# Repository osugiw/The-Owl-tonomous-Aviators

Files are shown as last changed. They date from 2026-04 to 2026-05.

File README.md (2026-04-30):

# Owl-tonomous Car 🚗🦉

This project implements a small autonomous vehicle capable of following a predefined track using computer vision and control techniques. The system was developed as part of the ELEC 553 course.

## Overview

The vehicle uses a camera and onboard processing (Raspberry Pi) to detect lane markings and navigate the track in real time. Steering and speed are controlled using PID controllers, enabling stable and smooth motion.

## Features

- Lane detection using OpenCV and HSV color segmentation  
- Polynomial fitting for trajectory estimation  
- Steering control using PID  
- Speed regulation using an optical encoder for feedback  
- Red signal detection for stop behavior  
- Object detection using YOLOv5 on Raspberry Pi  

## System Architecture

- **Camera**: captures real-time video of the track  
- **Raspberry Pi**: processes images and runs control algorithms  
- **Servo Motor**: controls steering  
- **DC Motor**: drives the vehicle forward  
- **Optical Encoder**: measures motor speed for closed-loop control  

## Lane Detection

The system detects blue tape marking the track using HSV color segmentation. A region of interest is applied to focus on relevant areas of the image. Detected lane pixels are used to fit second-order polynomials, and the center trajectory is computed from the lane boundaries. A look-ahead point is then used to estimate the steering angle.

## Control

Steering is controlled using a PID controller based on the difference between the desired heading (straight) and the estimated steering angle. Speed is regulated using a second PID loop, which uses feedback from an optical encoder to maintain a target RPM.

## Red Signal Detection

Red markers placed on the track are detected using color segmentation. The first detected marker causes the vehicle to stop briefly before continuing, while the second marker triggers a full stop.

## Object Detection

The system also integrates object detection using YOLOv5 running on the Raspberry Pi. The official Ultralytics repository was used, and images were resized to 320×320 for efficient inference. The system achieves approximately 3.8 FPS on test images, with performance varying during live streaming due to latency and hardware constraints.

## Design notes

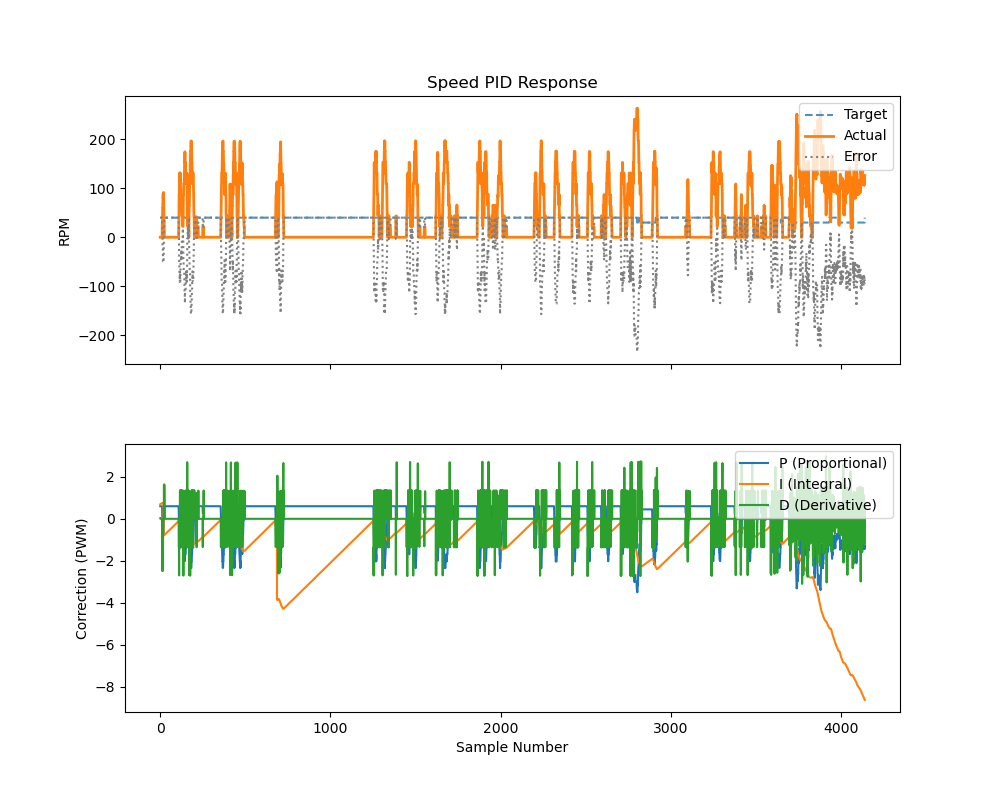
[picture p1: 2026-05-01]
PID_speed.png

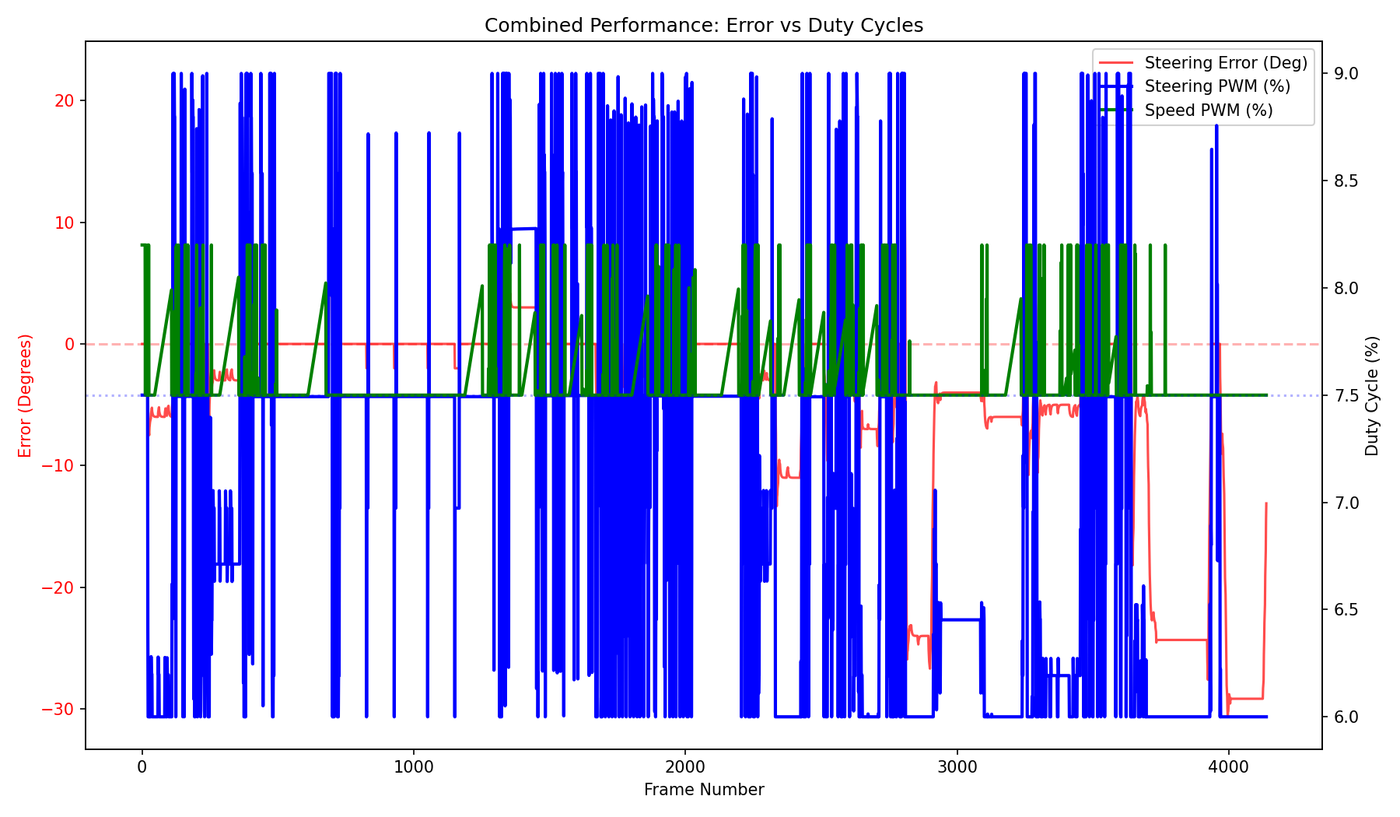
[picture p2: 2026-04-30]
DutyCycle_SpeedSteering.png

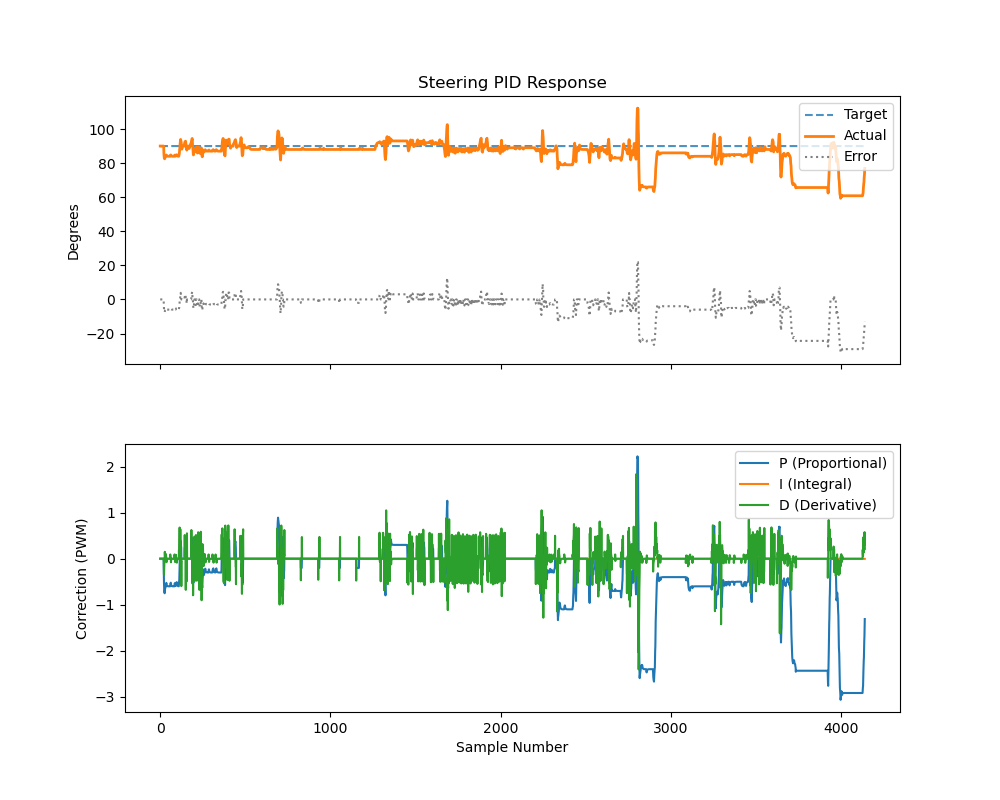
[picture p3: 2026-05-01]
PID_steering.png

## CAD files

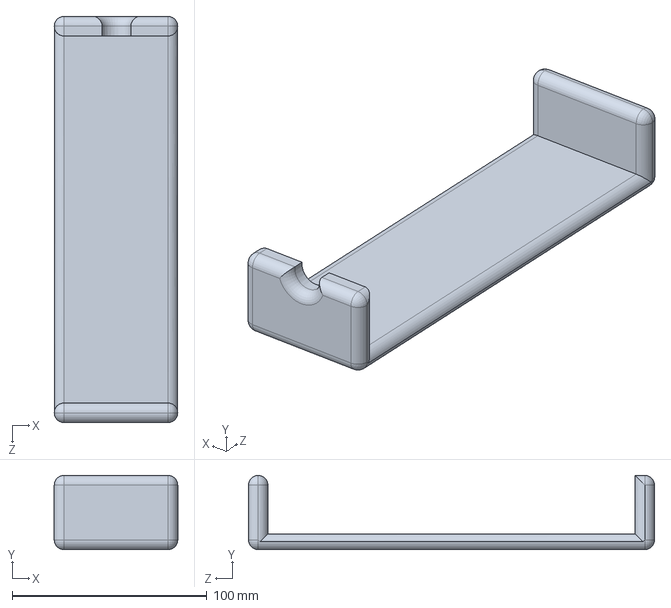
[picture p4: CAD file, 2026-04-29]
3D Print/CameraMount.SLDPRT
63.5 x 38.1 x 208.6 mm

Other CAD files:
3D Print/CameraMount.STL

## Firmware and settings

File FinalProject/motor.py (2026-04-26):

import matplotlib
# Use the 'Agg' backend to avoid memory-heavy GUI windows
matplotlib.use('Agg') 
import numpy as np

import matplotlib.pyplot as plt
import RPi.GPIO as GPIO
import time
from time import sleep

# Minimum DC PWM
min_speed_pwm = 7.5
max_speed_pwm = 8.2
default_speed_pwm = 8.1
steering_forward = 7.5 
steering_right = 9.0
steering_left = 6.0 

# PID Controller
speed_Kp = 0.001
speed_Ki = 0.005
speed_Kd = 0.00003

steering_Kp = -0.015
steering_Ki = 0.0
steering_Kd = 0.001

# Plot for Tuning PID
speed_plot = {
    "rpm_target"  : [],
    "rpm_err"     : [],
    "rpm_actual"  : [],
    "p"           : [], 
    "i"           : [],
    "d"           : [],
}
steering_plot = {
    "steering_target"  : [],
    "steering_err"     : [],
    "steering_actual"  : [],
    "p"           : [], 
    "i"           : [],
    "d"           : [],
}


"""
    Control Motor
"""
class MotorController:
    def __init__(self, speed_pin=18, steering_pin=19):
        self.speed_pin = speed_pin
        self.steering_pin = steering_pin

        # PID Controller Init
        self.pid_speed_integral = 0
        self.pid_speed_last_error = 0
        self.pid_speed_last_time = time.time()
        self.pid_steering_integral = 0
        self.pid_steering_last_error = 0
        self.pid_steering_last_time = time.time()
        
        # Pin Initialization
        GPIO.setmode(GPIO.BCM)
        GPIO.setup(self.speed_pin, GPIO.OUT)
        GPIO.setup(self.steering_pin, GPIO.OUT)

        self.speed_pwm = GPIO.PWM(self.speed_pin, 50) # set the frequency to 50 Hz 
        self.steering_pwm = GPIO.PWM(self.steering_pin, 50) # set the frequency to 50 Hz 

        self.speed_pwm.start(7.5) # Don't change the 7.5 DC because it is for initialization
        # sleep(0.5)
        # self.speed_pwm.start(10.0) # Don't change the 7.5 DC because it is for initialization
        # sleep(0.1)
        # self.speed_pwm.start(5.0) # Don't change the 7.5 DC because it is for initialization
        # sleep(0.5)
        # self.speed_pwm.start(7.5) # Don't change the 7.5 DC because it is for initialization
        self.steering_pwm.start(steering_forward) # Start with the specified duty cycle

    def set_speed(self, duty_cycle):
        self.speed_pwm.ChangeDutyCycle(duty_cycle)

    def set_steering(self, angle="forward"):
        if angle == "forward":
            self.steering_pwm.ChangeDutyCycle(steering_forward)
        elif angle == "right":
            self.steering_pwm.ChangeDutyCycle(steering_right)
        elif angle == "left":
            self.steering_pwm.ChangeDutyCycle(steering_left)

    def stop(self):
        self.set_speed(0)
        self.speed_pwm.stop()
        self.steering_pwm.stop()
        GPIO.cleanup()

    def update_speed(self, target_RPM, measured_RPM):
        current_time = time.time()
        dt = current_time - self.pid_speed_last_time

        # Prevent zero DC
        if dt < 0.010:
            return 7.5
        
        # Calculate the difference between target and measured
        error = target_RPM - measured_RPM
        
        # PID Calculation
        _P = speed_Kp * error
        self.pid_speed_integral += error * dt   # Accumulate error overtime for calculating Integral part
        _I = speed_Ki * self.pid_speed_integral
        _D =  speed_Kd * ((error - self.pid_speed_last_error) / dt)
        
        # New adjustment
        output = min_speed_pwm + (_P + _I + _D)
        final_pwm = max(min_speed_pwm, min(max_speed_pwm, output))  # ADC Mapping for final Duty Cycle PWM

        # print(f"[Speed - RPM] Measured: {measured_RPM:6.1f} | Error: {error:6.1f} --- PID({_P:1.3f}, {_I:1.3f}, {_D:1.3f}) -> PWM: {final_pwm:5.3f}%")

        # For tuning the PID
        speed_plot["rpm_target"].append(target_RPM)
        speed_plot["rpm_actual"].append(measured_RPM)
        speed_plot["rpm_err"].append(error) 
        speed_plot["p"].append(_P) 
        speed_plot["i"].append(_I)
        speed_plot["d"].append(_D)

        # Update state
        self.pid_speed_last_time = current_time
        self.pid_speed_last_error = error

        return final_pwm

    def update_steering(self, target_angle, actual_angle):
        if actual_angle is None:
            return 7.5  # Neutral/Straight

        now = time.time()
        dt = now - self.pid_steering_last_time
        if dt < 0.01: return 7.5

        # 1. Calculate Error (Target is 90)
        # Using the reference logic: -(actual - 90)
        error = -(actual_angle - target_angle)
        
        # 2. PD Calculation
        _P = steering_Kp * error
        _D = steering_Kd * (error - self.pid_steering_last_error) / dt
        
        # 3. Reference Logic: Clip the raw correction first
        # This prevents the "Integral/Derivative spike" seen in your plot
        raw_correction = _P + _D
        raw_correction = max(min(raw_correction, 1.0), -1.0)

        # 4. Apply Sensitivity and Neutral Offset
        # 7.5 is usually the "zero_turn" center for servos
        final_pwm = 7.5 + (raw_correction * 2.6)
        
        # 5. Final Hardware Clamp
        final_pwm = max(steering_left, min(steering_right, final_pwm))

        # Save data for your plots
        steering_plot["steering_target"].append(target_angle)
        steering_plot["steering_actual"].append(actual_angle)
        steering_plot["steering_err"].append(error) 
        steering_plot["p"].append(_P)
        steering_plot["i"].append(0) # We are using PD now, so I is 0
        steering_plot["d"].append(_D)

        self.pid_steering_last_time = now
        self.pid_steering_last_error = error

        return final_pwm
    
    def save_pid_plot(self, data_dict, filename, title, y_label_top):
        """Helper function to handle all PID plotting logic."""
        # 1. Check for data and synchronized keys
        if not data_dict or len(next(iter(data_dict.values()))) < 2:
            print(f"Not enough data to plot {title}.")
            return

        try:
            # 2. Sync lengths and create snapshots
            min_len = min(len(data_dict[k]) for k in data_dict.keys())
            
            # Map the specific keys for speed/steering dynamically
            # We assume standard keys: p, i, d and specific target/actual/err keys
            p_val = np.array(data_dict["p"][:min_len])
            i_val = np.array(data_dict["i"][:min_len])
            d_val = np.array(data_dict["d"][:min_len])
            
            # Identify which keys to use for the top plot
            k_target = [k for k in data_dict if "target" in k][0]
            k_actual = [k for k in data_dict if "actual" in k][0]
            k_err    = [k for k in data_dict if "err" in k][0]

            fig, (ax1, ax2) = plt.subplots(2, 1, figsize=(10, 8), sharex=True)

            # Top Plot: Performance
            ax1.plot(np.array(data_dict[k_target][:min_len]), label="Target", linestyle="--", alpha=0.8)
            ax1.plot(np.array(data_dict[k_actual][:min_len]), label="Actual", linewidth=2)
            ax1.plot(np.array(data_dict[k_err][:min_len]), label="Error", linestyle=":", color='gray')
            ax1.set_ylabel(y_label_top)
            ax1.set_title(title)
            ax1.legend(loc='upper right')

            # Bottom Plot: PID Terms
            ax2.plot(p_val, label="P (Proportional)")
            ax2.plot(i_val, label="I (Integral)")
            ax2.plot(d_val, label="D (Derivative)")
            ax2.set_ylabel("Correction (PWM)")
            ax2.set_xlabel("Sample Number")
            ax2.legend(loc='upper right')

            plt.subplots_adjust(hspace=0.3) 
            plt.savefig(filename, dpi=100)
            plt.close(fig)
            print(f"Successfully saved: {filename}")

        except Exception as e:
            print(f"Failed to plot {title}: {e}")

    # --- Simplified Callers ---
    def plot_speed_PID(self):
        self.save_pid_plot(speed_plot, "PID_speed.png", "Speed PID Response", "RPM")

    def plot_steering_PID(self):
        self.save_pid_plot(steering_plot, "PID_steering.png", "Steering PID Response", "Degrees")


# if __name__ == "__main__":
#     motor_controller = MotorController() # Initialize motor controller with default pins and steering angle
#     try:
#         while True:
#             # Move forward
#             motor_controller.set_steering("forward")
#             motor_controller.set_speed(default_speed_pwm)
#             sleep(0.5)
            
#             # Stop
#             motor_controller.set_speed(0)
#             sleep(0.5)
            
#             # Turn left
#             motor_controller.set_steering("left")
#             motor_controller.set_speed(default_speed_pwm-0.1) # Set speed back to default
#             sleep(1)
            
#             # Turn right
#             motor_controller.set_steering("right")
#             motor_controller.set_speed(default_speed_pwm-0.1) # Set speed back to default
#             sleep(1)
            
#             # Turn straight
#             motor_controller.set_steering("left")
#             motor_controller.set_speed(default_speed_pwm-0.1) # Set speed back to default
#             sleep(0.5)
#     except KeyboardInterrupt:
#         pass

#     # Terminate motor controller and clean up GPIO settings
#     motor_controller.stop()

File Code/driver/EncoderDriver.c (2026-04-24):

#include <linux/module.h>
#include <linux/init.h>
#include <linux/of_device.h>
#include <linux/kernel.h>
#include <linux/gpio.h>
#include <linux/gpio/consumer.h>
#include <linux/platform_device.h>
#include <linux/interrupt.h>
#include <linux/ktime.h>
#include <linux/mod_devicetable.h>

// Timer variables
ktime_t now;
static ktime_t lastTime;

// GPIO variables
unsigned int irq_enc_num;
struct gpio_desc *enc;
static int enc_count = 0;
module_param(enc_count, int, 0644);

/**
 * @brief Interrupt service routine is called, when interrupt is triggered
 */
static irqreturn_t gpio_irq_handler(int irq, void *dev_id)
{
	s64 time_diff_ns;

	// Verify debounce time
	now = ktime_get();
	time_diff_ns = ktime_to_ns(ktime_sub(now, lastTime));

	// Debounce is 1ms because we have 20-hole wheel
	if(time_diff_ns < 10000000)
	{
		printk("Pressed is ignored\n");
		return IRQ_HANDLED;
	}

	// Count encoder
    enc_count++;
	lastTime = ktime_get();

  return IRQ_HANDLED;
}

// probe function
static int enc_probe(struct platform_device *pdev)
{
  	// Initiate Button
  	struct device *dev = &pdev->dev;
  	enc = devm_gpiod_get_index(dev, "enc", 0, GPIOD_IN);
  
  	// Register Button IRQ
  	irq_enc_num = gpiod_to_irq(enc);
  	if(request_irq(irq_enc_num, gpio_irq_handler, IRQF_TRIGGER_FALLING, "enc_irq", NULL) != 0){
		printk("Error!\nCan not request interrupt nr.: %d\n", irq_enc_num);
		return -1;
	}
	printk("Sucessfully insert Encoder module\n");
	return 0;
}

// remove function
static void enc_remove(struct platform_device *pdev)
{
	// Release IRQ
  	free_irq(irq_enc_num, NULL);
  	printk("Removing encoder\n");
}

static struct of_device_id matchy_match[] = {
    { .compatible = "speed_encoder"},
    {/* leave alone - keep this here (end node) */},
};

// platform driver object
static struct platform_driver enc_drv = {
	.probe	 = enc_probe,
	.remove	 = enc_remove,
	.driver	 = {
	       .name  = "Encoder driverr",
	       .owner = THIS_MODULE,
	       .of_match_table = matchy_match,
	},
};

module_platform_driver(enc_drv);

MODULE_DESCRIPTION("Encoder driver for Final Project - ELEC 553");
MODULE_AUTHOR("Owlt-onomous");
MODULE_LICENSE("GPL v2");
MODULE_ALIAS("platform:encoder_driver");

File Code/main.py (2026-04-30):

"""
@Description: 
    This project was developed as the final project for ELEC 553. The objective was to design and implement an autonomous vehicle capable of navigating a predefined track using computer vision and control techniques.
@Contributor: 
    Ashley Garcia, Mehul Goel, Sugiarto Wibowo, Valeria Itrat Herrera
"""

import time
import cv2
from motor import MotorController
from encoder import MotorEncoder
from poly_lane2 import LaneTracker as PolyLaneTracker

if __name__ == "__main__":
    motor_ctrl = MotorController()
    motor_enc = MotorEncoder()
    poly_lane_detect = PolyLaneTracker()

    count_frame = 0
    red_cnt = 0
    red_flag = False

    prev_steering = 90
    pred_alpha = 0.3

    red_box_thr = 2500

    try:
        while True:
            # Process the land detection and robot steering angle
            time.sleep(0.02)
            actual_steering, red, img = poly_lane_detect.get_lane_data()
            count_frame += 1
            
            if img is not None:
                cv2.imshow("Perfected View", img)
                if cv2.waitKey(1) & 0xFF == ord('q'):
                    break

            # Box red detection
            if count_frame % 3 == 0:
                count_frame = 0
                if red is not None and red > red_box_thr and not red_flag:
                    red_cnt += 1
                    red_flag = True

                    print(f"Red Box Detected! (Size: {red}). Stopping the car! - Box count {red_cnt}")

                    if red_cnt == 1:
                        print("First stop detected!")
                        motor_ctrl.set_speed(0)
                        motor_ctrl.set_steering_pid(7.5)
                        time.sleep(5)
                        motor_ctrl.set_speed(8.1)
                        time.sleep(2)
                    elif red_cnt == 2:
                        print("Second stop detected!")
                        motor_ctrl.stop()
                        break

                if (red is None or red <= red_box_thr) and red_flag:
                    print("Red box disappeared, ready for next detection")
                    red_flag = False

            # Steering angle calculation and update
            if actual_steering is not None:
                delta = actual_steering - prev_steering

                if abs(actual_steering - 90) > 35:
                    print(f"[Warning] Extreme angle {actual_steering:.1f}, dampening")
                    actual_steering = prev_steering + (0.5 * delta)

                predicted_steering = actual_steering + (pred_alpha * delta)
                predicted_steering = max(50, min(130, predicted_steering))
                prev_steering = actual_steering
            else:
                predicted_steering = prev_steering

            print(f"Steering: {actual_steering} | Predicted: {predicted_steering:.1f}", end="\r")
            steering_pwm = motor_ctrl.update_steering(90, predicted_steering)
            motor_ctrl.set_steering_pid(steering_pwm)

            # Update the speed based on calcualted steering angle
            if actual_steering is not None and (actual_steering < 75 or actual_steering > 105):
                target_rpm = 30
            else:
                target_rpm = 40
            rpm = motor_enc.calculate_rpm()
            speed_pwm = motor_ctrl.update_speed(target_rpm, rpm)
            motor_ctrl.set_speed(speed_pwm)
    except KeyboardInterrupt:
        pass

    # Clear the pipeline and GPIOs
    motor_ctrl.stop()
    poly_lane_detect.clean_up()

    # Plot PID and data for debugging
    motor_ctrl.plot_speed_PID()
    motor_ctrl.plot_steering_PID()
    motor_ctrl.plot_combined_run()
    print("\nRobot terminated")

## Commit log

2026-04-16 fix bug in motor initalization
2026-04-17 added encoder driver
2026-04-24 adding motor encoder
2026-04-24 speed PID works, need tuning and camera tuning for lane
2026-04-26 encoder camera updates
2026-04-26 camera and steering updates
2026-04-29 latest update: servo steering problem
    [EncoderDriver.c, camera.py, encoder.py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]
2026-04-29 steering PID solved
2026-04-30 PID results
